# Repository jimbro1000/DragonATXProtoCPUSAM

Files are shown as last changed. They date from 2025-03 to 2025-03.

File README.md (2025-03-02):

# Dragon 32 ATX Prototype CPU and SAM

This repository contains the KiCad project files
to produce the CPU and SAM component board for my
ATX Prototype backplane.

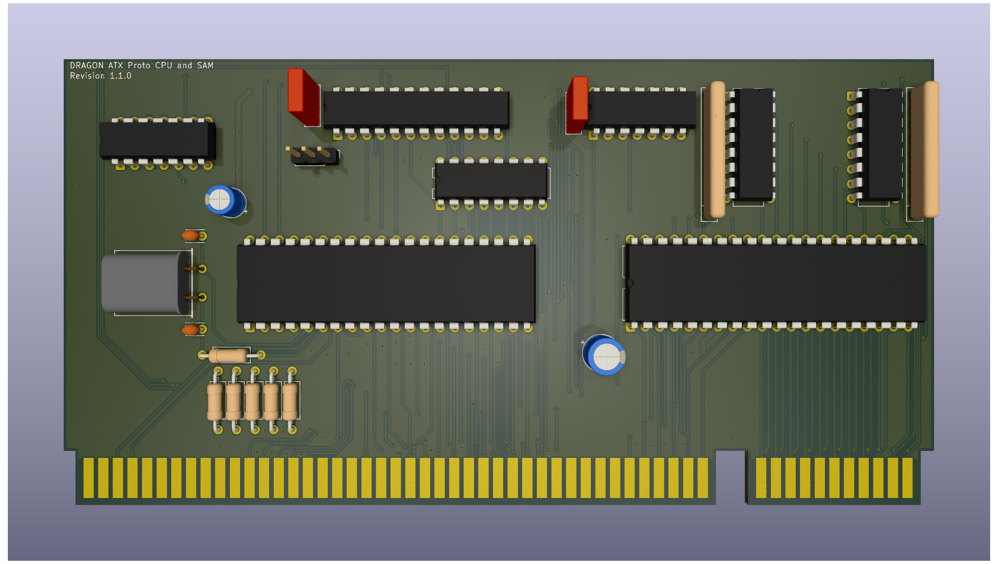
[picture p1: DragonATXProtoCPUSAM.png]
Render of PCB top


This design requires the ATX backplane board in order 
to operate
See https://github.com/jimbro1000/DragonATXProto

## Notes

Revision 1 of the board contains just a standard
SAM. Revision 2 will use the later version of the SAM
(74LS785) that provides 256 refresh cycles instead of 
the 128 of the original SAM (74LS783).

Revision 3 will utilise a synthetic version of the SAM
developed by Ciaran Anscomb.

The backplane includes a mounting point for a more
substantial synthetic implementation of the SAM that
means the SAM can be omitted completely on any of the
CPU/SAM board implementations

This design has been completed using KiCad 9. Earlier
versions of KiCad are not compatible.

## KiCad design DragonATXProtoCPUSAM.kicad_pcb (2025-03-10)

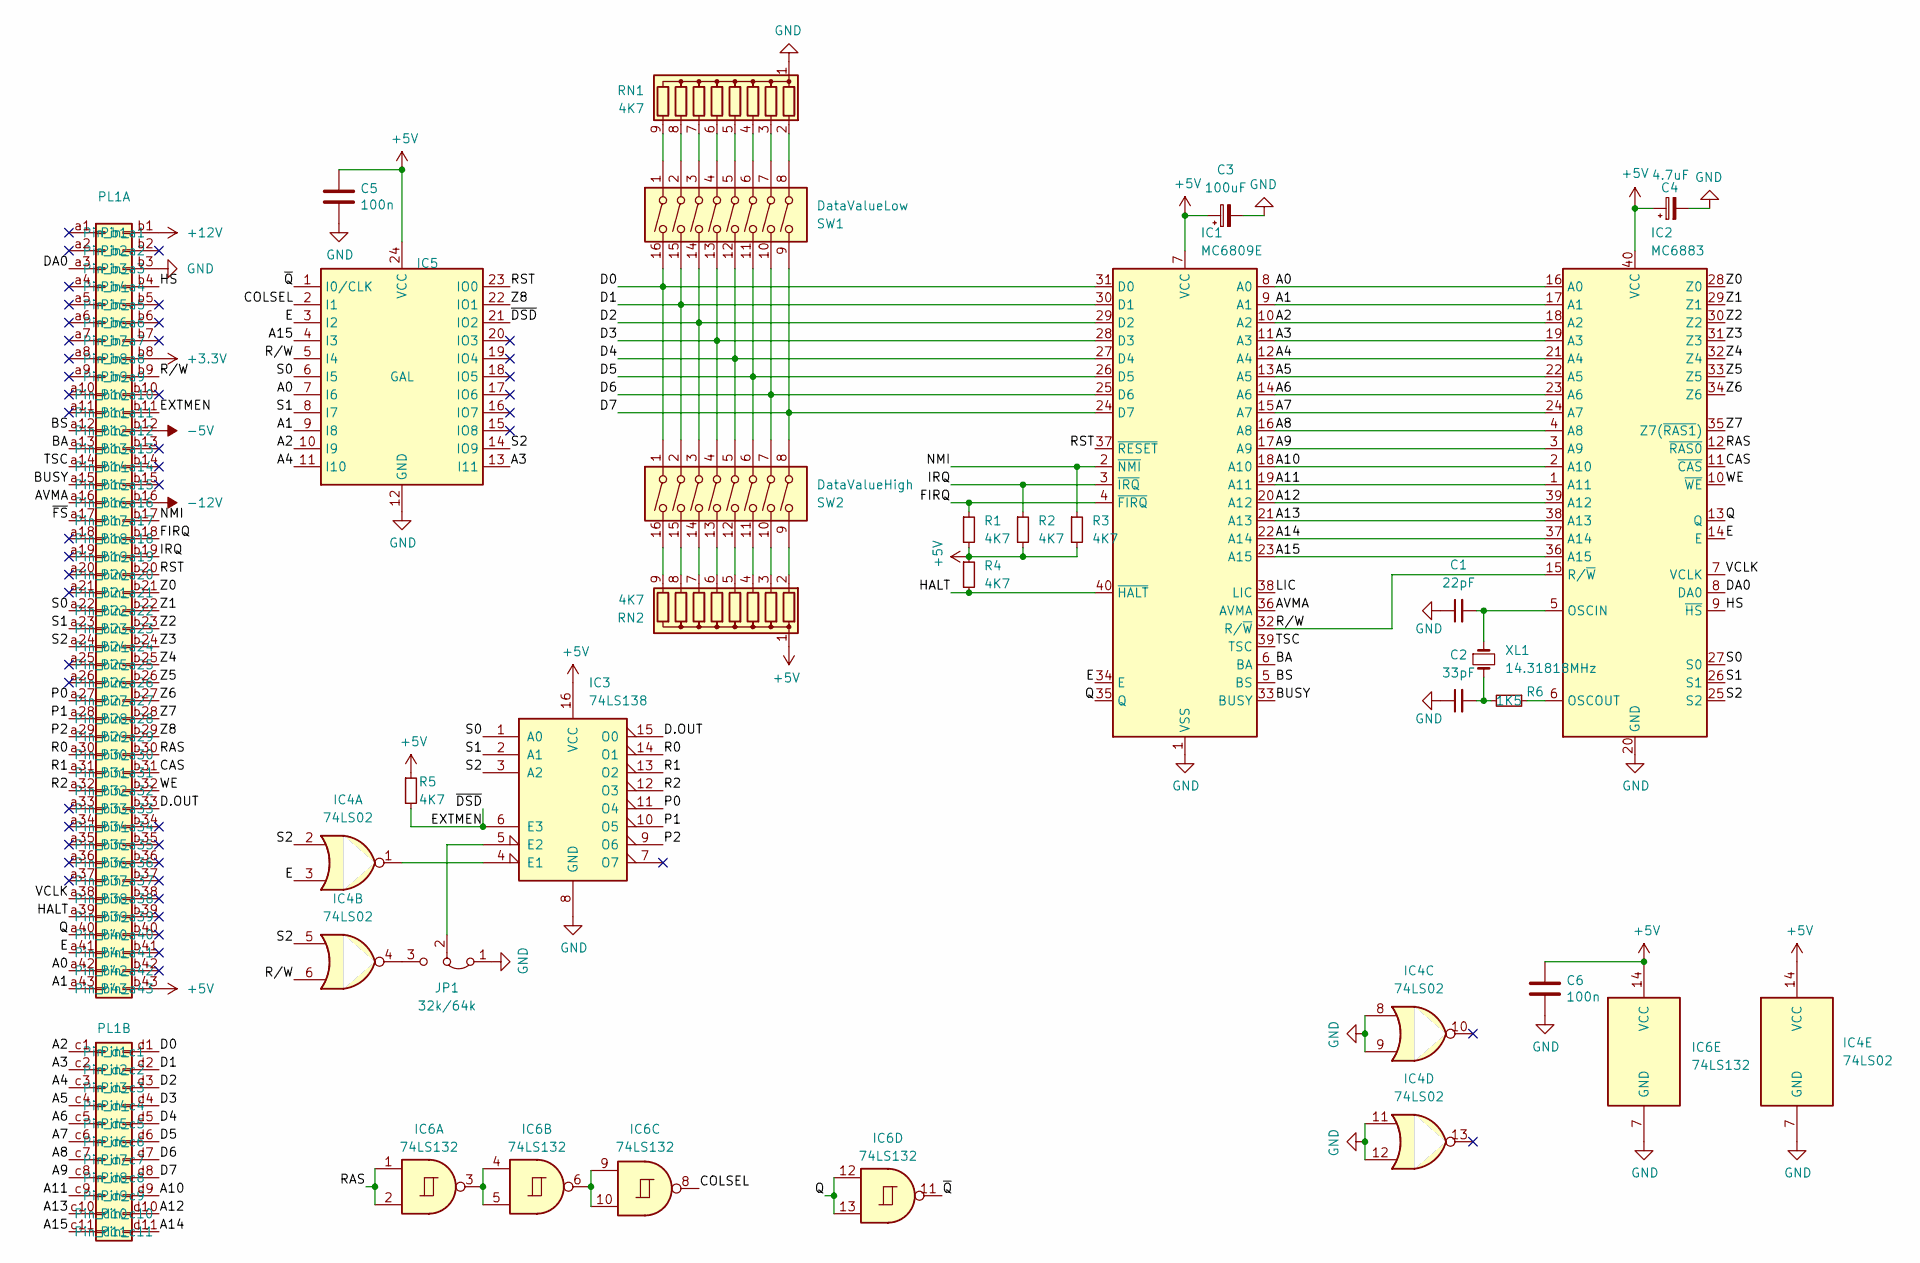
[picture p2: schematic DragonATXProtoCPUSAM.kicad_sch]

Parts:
C1: 22pF; C_Disc_D3.0mm_W2.0mm_P2.50mm; DigiKey 399-13930-1-ND
C2: 33pF; C_Disc_D3.0mm_W2.0mm_P2.50mm; DigiKey BC1007CT-ND
C3: 100uF; CP_Radial_D6.3mm_P2.50mm; DigiKey 732-8598-1-ND
C4: 4.7uF; CP_Radial_D5.0mm_P2.50mm; DigiKey 478-8984-1-ND
C5, C6: 100n; C_Rect_L7.0mm_W2.5mm_P5.00mm
IC1: MC6809E; DIP-40_W15.24mm
IC2: MC6883; DIP-40_W15.24mm
IC3: 74LS138; DIP-16_W7.62mm
IC4: 74LS02; DIP-14_W7.62mm
IC5: GAL; DIP-24_W7.62mm
IC6: 74LS132; DIP-14_W7.62mm
JP1: 32k/64k; PinHeader_1x03_P2.54mm_Vertical
PL1: Card_Edge
R1, R2, R3, R4, R5: 4K7; R_Axial_DIN0207_L6.3mm_D2.5mm_P10.16mm_Horizontal; DigiKey CF14JT4K70CT-ND
R6: 1K5; R_Axial_DIN0207_L6.3mm_D2.5mm_P10.16mm_Horizontal; DigiKey CF14JT1K50CT-ND
RN1, RN2: 4K7; R_Array_SIP9
SW1: DataValueLow; DIP-16_W7.62mm
SW2: DataValueHigh; DIP-16_W7.62mm
XL1: 14.31818MHz; Crystal_HC49-U_Horizontal; DigiKey CTX088-ND

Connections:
+3.3V: PL1.b8
+5V: C3.1, C4.1, C5.1, C6.1, IC1.7 (VCC), IC2.40 (VCC), IC3.16 (VCC), IC4.14 (VCC), IC5.24 (VCC), IC6.14 (VCC), PL1.b43, R1.2, R2.2, R3.2, R4.1, R5.1, RN2.1 (common)
+12V: PL1.b1
-5V: PL1.b12
-12V: PL1.b16
/A0: IC1.8 (A0), IC2.16 (A0), IC5.7 (I6), PL1.a42
/A1: IC1.9 (A1), IC2.17 (A1), IC5.9 (I8), PL1.a43
/A2: IC1.10 (A2), IC2.18 (A2), IC5.10 (I9), PL1.c1
/A3: IC1.11 (A3), IC2.19 (A3), IC5.13 (I11), PL1.c2
/A4: IC1.12 (A4), IC2.21 (A4), IC5.11 (I10), PL1.c3
/A5: IC1.13 (A5), IC2.22 (A5), PL1.c4
/A6: IC1.14 (A6), IC2.23 (A6), PL1.c5
/A7: IC1.15 (A7), IC2.24 (A7), PL1.c6
/A8: IC1.16 (A8), IC2.4 (A8), PL1.c7
/A9: IC1.17 (A9), IC2.3 (A9), PL1.c8
/A10: IC1.18 (A10), IC2.2 (A10), PL1.d9
/A11: IC1.19 (A11), IC2.1 (A11), PL1.c9
/A12: IC1.20 (A12), IC2.39 (A12), PL1.d10
/A13: IC1.21 (A13), IC2.38 (A13), PL1.c10
/A14: IC1.22 (A14), IC2.37 (A14), PL1.d11
/A15: IC1.23 (A15), IC2.36 (A15), IC5.4 (I3), PL1.c11
/AVMA: IC1.36 (AVMA), PL1.a16
/BA: IC1.6 (BA), PL1.a13
/BS: IC1.5 (BS), PL1.a12
/BUSY: IC1.33 (BUSY), PL1.a15
/CAS: IC2.11 (~CAS), PL1.b31
/COLSEL: IC5.2 (I1), IC6.8
/D0: IC1.31 (D0), PL1.d1, SW1.16, SW2.1
/D1: IC1.30 (D1), PL1.d2, SW1.15, SW2.2
/D2: IC1.29 (D2), PL1.d3, SW1.14, SW2.3
/D3: IC1.28 (D3), PL1.d4, SW1.13, SW2.4
/D4: IC1.27 (D4), PL1.d5, SW1.12, SW2.5
/D5: IC1.26 (D5), PL1.d6, SW1.11, SW2.6
/D6: IC1.25 (D6), PL1.d7, SW1.10, SW2.7
/D7: IC1.24 (D7), PL1.d8, SW1.9, SW2.8
/D.OUT: IC3.15 (O0), PL1.b33
/DA0: IC2.8 (DA0), PL1.a3
/E: IC1.34 (E), IC2.14 (E), IC4.3, IC5.3 (I2), PL1.a41
/EXTMEN: IC3.6 (E3), IC5.21 (IO2), PL1.b11, R5.2
/FIRQ: IC1.4 (~FIRQ), PL1.b18, R1.1
/HALT: IC1.40 (~HALT), PL1.a39, R4.2
/HS: IC2.9 (~HS), PL1.b4
/IRQ: IC1.3 (~IRQ), PL1.b19, R2.1
/LIC: IC1.38 (LIC)
/NMI: IC1.2 (~NMI), PL1.b17, R3.1
/P0: IC3.11 (O4), PL1.a27
/P1: IC3.10 (O5), PL1.a28
/P2: IC3.9 (O6), PL1.a29
/Q: IC1.35 (Q), IC2.13 (Q), IC6.12, IC6.13, PL1.a40
/R0: IC3.14 (O1), PL1.a30
/R1: IC3.13 (O2), PL1.a31
/R2: IC3.12 (O3), PL1.a32
/RAS: IC2.12 (~RAS0), IC6.1, IC6.2, PL1.b30
/RST: IC1.37 (~RESET), IC5.23 (IO0), PL1.b20
/R/W: IC1.32 (R/~W), IC2.15 (R/~W), IC4.6, IC5.5 (I4), PL1.b9
/S0: IC2.27 (S0), IC3.1 (A0), IC5.6 (I5), PL1.a22
/S1: IC2.26 (S1), IC3.2 (A1), IC5.8 (I7), PL1.a23
/S2: IC2.25 (S2), IC3.3 (A2), IC4.2, IC4.5, IC5.14 (IO9), PL1.a24
/TSC: IC1.39 (TSC), PL1.a14
/VCLK: IC2.7 (VCLK), PL1.a38
/WE: IC2.10 (~WE), PL1.b32
/Z0: IC2.28 (Z0), PL1.b21
/Z1: IC2.29 (Z1), PL1.b22
/Z2: IC2.30 (Z2), PL1.b23
/Z3: IC2.31 (Z3), PL1.b24
/Z4: IC2.32 (Z4), PL1.b25
/Z5: IC2.33 (Z5), PL1.b26
/Z6: IC2.34 (Z6), PL1.b27
/Z7: IC2.35 (Z7(~RAS1)), PL1.b28
/Z8: IC5.22 (IO1), PL1.b29
/~FS: PL1.a17
/~Q: IC5.1 (I0/CLK), IC6.11
GND: C1.1, C2.1, C3.2, C4.2, C5.2, C6.2, IC1.1 (VSS), IC2.20 (GND), IC3.8 (GND), IC4.7 (GND), IC4.8, IC4.9, IC4.11, IC4.12, IC5.12 (GND), IC6.7 (GND), JP1.1 (A), PL1.b3, RN1.1 (common)
unnamed: C2.2, R6.2, XL1.2
unnamed: C1.2, IC2.5 (OSCIN), XL1.1
unnamed: IC2.6 (OSCOUT), R6.1
unnamed: IC3.4 (E1), IC4.1
unnamed: IC3.5 (E2), JP1.2 (C)
unnamed: IC6.3, IC6.4, IC6.5
unnamed: IC6.6, IC6.9, IC6.10
unnamed: IC4.4, JP1.3 (B)
unnamed: RN1.2 (R1), SW1.8
unnamed: RN1.3 (R2), SW1.7
unnamed: RN1.4 (R3), SW1.6
unnamed: RN1.5 (R4), SW1.5
unnamed: RN1.6 (R5), SW1.4
unnamed: RN1.7 (R6), SW1.3
unnamed: RN1.8 (R7), SW1.2
unnamed: RN1.9 (R8), SW1.1
unnamed: RN2.2 (R1), SW2.9
unnamed: RN2.3 (R2), SW2.10
unnamed: RN2.4 (R3), SW2.11
unnamed: RN2.5 (R4), SW2.12
unnamed: RN2.6 (R5), SW2.13
unnamed: RN2.7 (R6), SW2.14
unnamed: RN2.8 (R7), SW2.15
unnamed: RN2.9 (R8), SW2.16

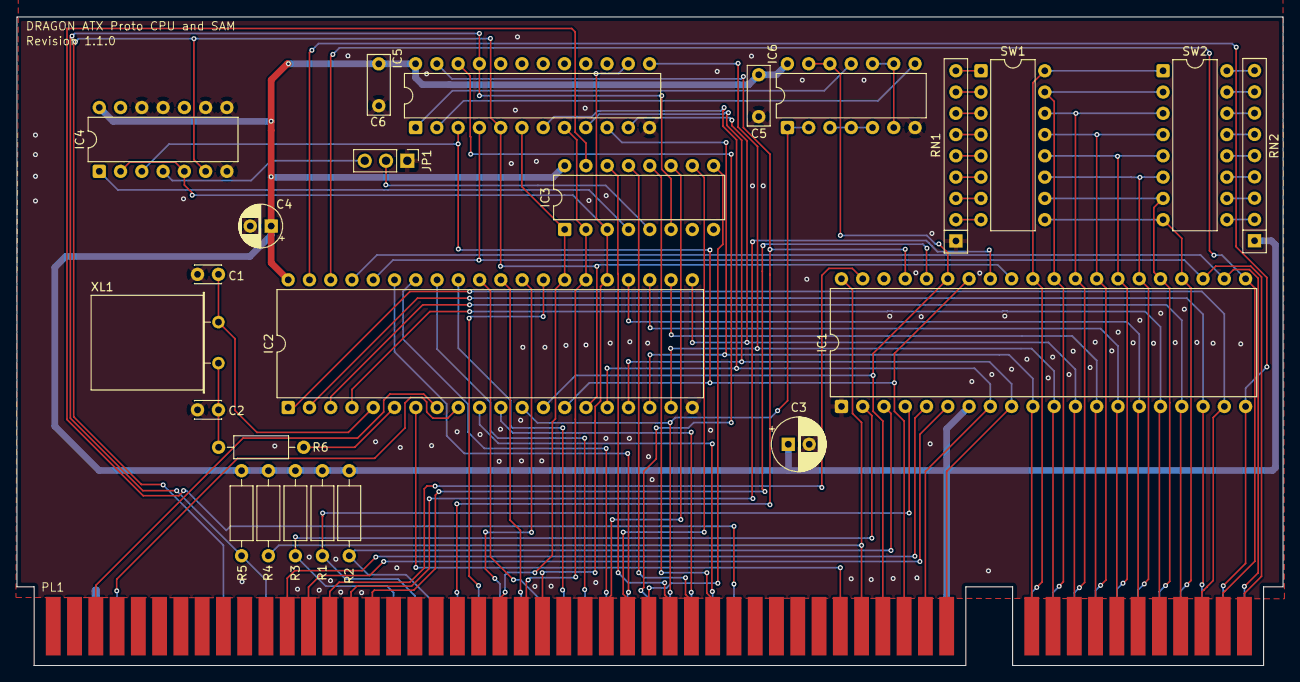
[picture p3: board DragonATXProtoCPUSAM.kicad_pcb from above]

Board: 2 copper layers, 151.2 x 77.4 mm, 25 parts (0 on the bottom side), 91 nets.

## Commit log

2025-03-02 add 256K banker
    [DragonATXProtoCPUSAM.kicad_pcb, DragonATXProtoCPUSAM.kicad_sch]
2025-03-10 Include pull-up/down on data lines to allow quick forcing on selected inputs (for NOP)
    [DragonATXProtoCPUSAM.kicad_pcb, DragonATXProtoCPUSAM.kicad_sch]
